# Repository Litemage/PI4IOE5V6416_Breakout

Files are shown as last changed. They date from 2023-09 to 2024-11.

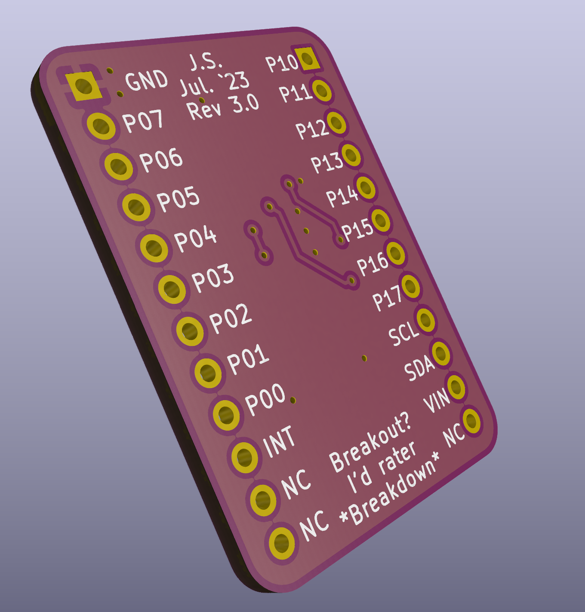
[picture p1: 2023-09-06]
Photos/Board_Back.png

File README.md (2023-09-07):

# Repo Description
This project contains a breakout board for the Diodes Inc. PI4IOE5V6416 16 channel I2C I/O expander, as well as a C driver, for easier incorporation into your projects.

[The datasheet can be found here](https://www.diodes.com/assets/Datasheets/PI4IOE5V6416.pdf).

# Hardware
The ECad tool of choice is KiCad for this project. 

Manufacturing files for revision 3.0 are available in the **/Manufacturing** directory.

Photos of the board are available in **/photos**

The schematic is available in the root directory as a pdf. 

# Driver \(C\)
The C driver is designed to be implementation-agnostic. I recommend reading through the header files to gain a better understanding of the driver itself, and what's available. Regardless, the driver works off of a handle principle:

You create a device handle that is populated with call-backs to all the different functions needed to communicate with the device (read / write). 

This handle is then passed to all the functions in the public API which read/write to the device.

There is currently one driver implementation example under **/Examples**. Open an issue for another example if the simple one isn't enough as a quick-start to the driver.

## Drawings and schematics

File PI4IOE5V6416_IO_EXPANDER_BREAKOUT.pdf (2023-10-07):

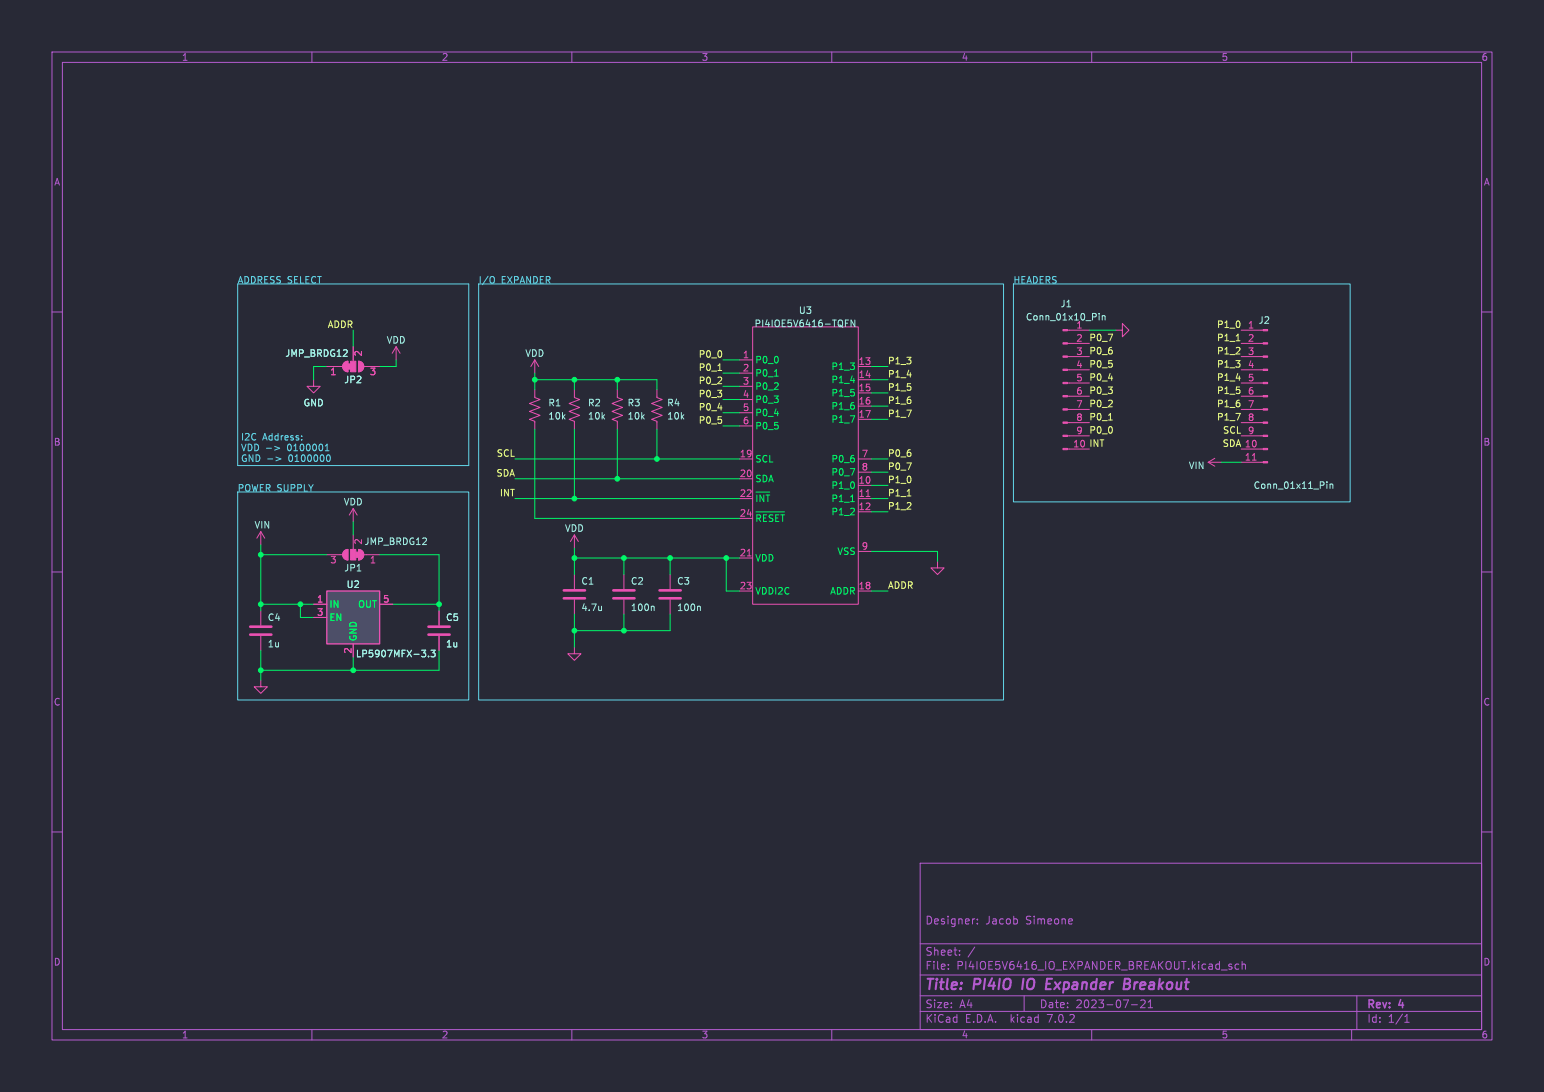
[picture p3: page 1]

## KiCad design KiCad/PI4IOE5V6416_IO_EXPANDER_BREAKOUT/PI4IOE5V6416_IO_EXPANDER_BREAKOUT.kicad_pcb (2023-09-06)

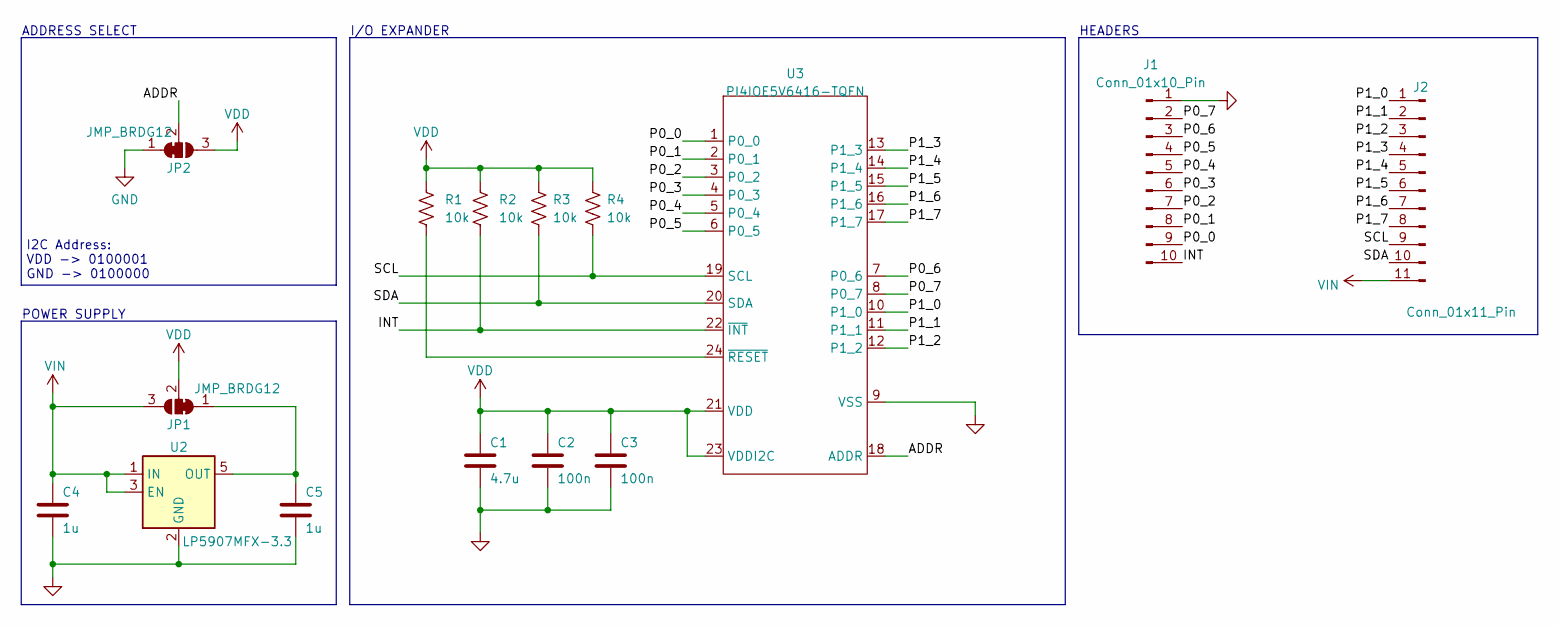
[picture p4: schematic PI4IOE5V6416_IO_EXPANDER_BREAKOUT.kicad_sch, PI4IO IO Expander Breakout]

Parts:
C1: 4.7u; C_0603_1608Metric
C2, C3: 100n; C_0603_1608Metric
C4, C5: 1u; C_0603_1608Metric
J1: Conn_01x10_Pin; PinHeader_1x10_P2.54mm_Vertical
J2: Conn_01x11_Pin; PinHeader_1x11_P2.54mm_Vertical
JP1, JP2: JMP_BRDG12; SolderJumper-3_P1.3mm_Bridged12_RoundedPad1.0x1.5mm
R1, R2, R3, R4: 10k; R_0603_1608Metric
U2: LP5907MFX-3.3; SOT-23-5
U3: PI4IOE5V6416-TQFN; TQFN-24-1EP_4x4mm_P0.5mm_EP2.1x2.1mm

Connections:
/ADDR: JP2.2 (C), U3.18 (ADDR)
/INT: J1.10, R2.2, U3.22 (~INT)
/P0_0: J1.9, U3.1 (P0_0)
/P0_1: J1.8, U3.2 (P0_1)
/P0_2: J1.7, U3.3 (P0_2)
/P0_3: J1.6, U3.4 (P0_3)
/P0_4: J1.5, U3.5 (P0_4)
/P0_5: J1.4, U3.6 (P0_5)
/P0_6: J1.3, U3.7 (P0_6)
/P0_7: J1.2, U3.8 (P0_7)
/P1_0: J2.1, U3.10 (P1_0)
/P1_1: J2.2, U3.11 (P1_1)
/P1_2: J2.3, U3.12 (P1_2)
/P1_3: J2.4, U3.13 (P1_3)
/P1_4: J2.5, U3.14 (P1_4)
/P1_5: J2.6, U3.15 (P1_5)
/P1_6: J2.7, U3.16 (P1_6)
/P1_7: J2.8, U3.17 (P1_7)
/SCL: J2.9, R4.2, U3.19 (SCL)
/SDA: J2.10, R3.2, U3.20 (SDA)
GND: C1.2, C2.2, C3.2, C4.2, C5.2, J1.1, JP2.1 (A), U2.2 (GND), U3.9 (VSS)
unnamed: C5.1, JP1.1 (A), U2.5 (OUT)
unnamed: R1.2, U3.24 (~RESET)
VDD: C1.1, C2.1, C3.1, JP1.2 (C), JP2.3 (B), R1.1, R2.1, R3.1, R4.1, U3.21 (VDD), U3.23 (VDDI2C)
VIN: C4.1, J2.11, JP1.3 (B), U2.1 (IN), U2.3 (EN)

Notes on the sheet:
POWER SUPPLY
ADDRESS SELECT
HEADERS
I2C Address: VDD -> 0100001 GND -> 0100000
I/O EXPANDER

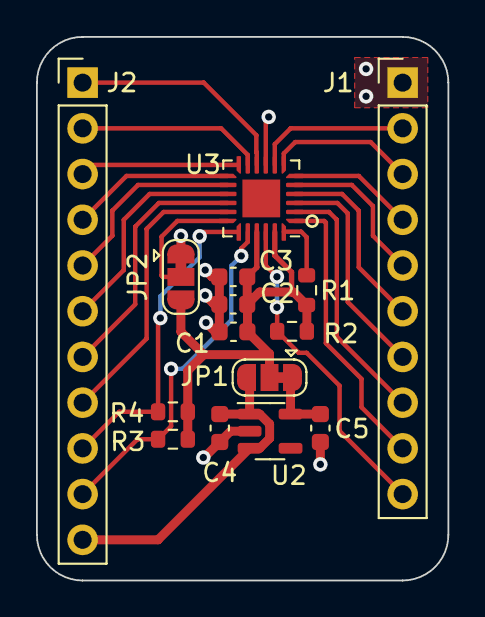
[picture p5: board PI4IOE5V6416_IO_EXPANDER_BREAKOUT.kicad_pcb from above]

Board: 2 copper layers, 22.9 x 30.2 mm, 15 parts (0 on the bottom side), 25 nets.

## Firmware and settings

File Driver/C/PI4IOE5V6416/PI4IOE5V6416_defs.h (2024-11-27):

/**
 * \file PI4IOE5V6416_defs.h
 * \authors Jacob Simeone (jsimeone0105@gmail.com)
 * \brief Macros for PI4IOE5V6416 driver
 * \date 2023-07-22
 * 
 */

#ifndef __PI4IOE5V6416_DEFS_H__
#define __PI4IOE5V6416_DEFS_H__

#include <stdint.h>
#include <stddef.h>

// DEFINITIONS =================================================================

/**
 * 
 * Signals to I2C read function to not specify the register address, resulting in
 * the driver reading from the "current" register, stored on the IC's register pointer
 * register. 
 * 
 * Only valid for reading
 * 
 */

#define PI4IO_REG_CURRENT         (0xFF)

#define PI4IO_ADDR_PRM            (0x20)
#define PI4IO_ADDR_SEC            (0x21)

// ========== Errors ==========

#define PI4IO_ERR_BASE            (0)
#define PI4IO_OK                  (PI4IO_ERR_BASE - 0)
#define PI4IO_ERR_COMM            (PI4IO_ERR_BASE - 1) // Communication to hardware failed
#define PI4IO_ERR_NULL_PTR        (PI4IO_ERR_BASE - 2)
#define PI4IO_ERR_ARG             (PI4IO_ERR_BASE - 3) // Invalid argument
#define PI4IO_ERR_CONFIG          (PI4IO_ERR_BASE - 4) // Configuration error
#define PI4IO_ERR_ADDR            (PI4IO_ERR_BASE - 5) // Invalid address

// ========== Registers ==========

#define PI4IO_REG_INPUT_PORT_0    (0x00)
#define PI4IO_REG_INPUT_PORT_1    (0x01)
#define PI4IO_REG_OUTPUT_PORT_0   (0x02)
#define PI4IO_REG_OUTPUT_PORT_1   (0x03)
#define PI4IO_REG_POLARITY_INV_0  (0x04)
#define PI4IO_REG_POLARITY_INV_1  (0x05)
#define PI4IO_REG_CONFIG_0        (0x06)
#define PI4IO_REG_CONFIG_1        (0x07)
#define PI4IO_REG_DRV_STREN_0_0   (0x40)
#define PI4IO_REG_DRV_STREN_0_1   (0x41)
#define PI4IO_REG_DRV_STREN_1_0   (0x42)
#define PI4IO_REG_DRV_STREN_1_1   (0x43)
#define PI4IO_REG_INPUT_LATCH_0   (0x44)
#define PI4IO_REG_INPUT_LATCH_1   (0x45)
#define PI4IO_REG_PU_PD_EN_0      (0x46)
#define PI4IO_REG_PU_PD_EN_1      (0x47)
#define PI4IO_REG_PU_PD_CFG_0     (0x48)
#define PI4IO_REG_PU_PD_CFG_1     (0x49)
#define PI4IO_REG_INT_MASK_0      (0x4A)
#define PI4IO_REG_INT_MASK_1      (0x4B)
#define PI4IO_REG_INT_STAT_0      (0x4C)
#define PI4IO_REG_INT_STAT_1      (0x4D)
#define PI4IO_REG_OUTPUT_PORT_CFG (0x4F)

#define PI4IO_REG_MAX             (PI4IO_REG_OUTPUT_PORT_CFG)

// TYPE DEFINITIONS ============================================================

/** 
 * Implement I2C communication with this function
 * 
 * Reference datasheet for more information: https://www.mouser.com/datasheet/2/115/PI4IOE5V6416-1488866.pdf
 * 
 * The process for writing to the PI4IOE5V6416 is:
 * 
 * - Master puts start condition onto bus
 * - Master puts slave address onto bus, with the write bit
 * - Slave acknowledges 
 * - Master puts register address on bus
 * - Slave acknowledges
 * - Master puts register data onto the bus
 * - Slave acknowledges
 * - Master puts stop condition on the bus
 * 
 * Ensure to reference datasheet for further details
 * 
 * Return -1 on failure, and 0 on success
 * 
*/
typedef int (*pi4io_i2c_write_fptr_t)(uint8_t addr, const uint8_t reg, const uint8_t val);

/**
 * Implement I2C communication with this function
 * 
 * Reference datasheet for more information: https://www.mouser.com/datasheet/2/115/PI4IOE5V6416-1488866.pdf
 * 
 * The process for reading data from the PI4IOE5V6416 is:
 * 
 * - Master puts start condition on the bus
 * - Master puts slave address on the bus with write bit
 * - Slave acknowledges
 * - Master puts register address on bus
 * - Slave acknowledges
 * - Master puts start condition on bus
 * - Master puts slave address on the bus with read bit
 * - Slave acknowledges
 * - Slave submits K bytes of read data
 * - Master acknowledges, unless enough data has been received, in which case the master will not-acknowledge
 * - Master puts stop condition on bus
 * 
 * Ensure to reference datasheet for further details
 * 
 * Return -1 on failure, and 0 on success
 * 
 */
typedef int (*pi4io_i2c_read_fptr_t)(uint8_t addr, const uint8_t reg, uint8_t *pBuf, const size_t bufSize);

/**
 * \brief Pointer to a function that controls the reset pin. If null, user is responsible for 
 * resetting device. 
 * 
 * NOTE: set to null if reset pin is not used. Note this will stop the driver from resetting the 
 * device on every init call
 * 
 * \param pinState Represents the requested state of the reset pin. 0 for low, 1 for high.
 * 
 */
typedef int (*pi4io_reset_pin_fptr_t)(uint8_t addr, const uint8_t pinState);

/**
 * \brief Delay for x microseconds
 * 
 * \param delay Number of uS to delay.
 * 
 */
typedef void (*pi4io_delay_us_fptr_t)(const uint64_t delay);

typedef struct
{
   pi4io_i2c_write_fptr_t write;  // I2C Write callback
   pi4io_i2c_read_fptr_t read;    // I2C Read Callback
   pi4io_reset_pin_fptr_t reset;  // Reset gpio function
   pi4io_delay_us_fptr_t delayUs; // Delay for some microseconds
   uint8_t addr;
} pi4io_dev_t;

typedef enum
{
   PI4IO_PORT_0 = 0,
   PI4IO_PORT_1 = 1,

   PI4IO_PORT_MAX,
} pi4io_port_num_t;
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

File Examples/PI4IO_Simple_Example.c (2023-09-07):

/**
 *
 * ========================= LICENSE =============================
 *
 * Licensed under the Apache License, Version 2.0 (the "License");
 * you may not use this file except in compliance with the License.
 * You may obtain a copy of the License at
 *
 *     http://www.apache.org/licenses/LICENSE-2.0
 *
 * Unless required by applicable law or agreed to in writing, software
 * distributed under the License is distributed on an "AS IS" BASIS,
 * WITHOUT WARRANTIES OR CONDITIONS OF ANY KIND, either express or implied.
 * See the License for the specific language governing permissions and
 * limitations under the License.
 *
 * ===============================================================
 *
 * @file PI4IO_Example.c
 * @author Jacob Simeone (jsimeone0105@gmail.com)
 *
 * @brief An example demonstrating the use of the PI4IOE5V6416 C driver included
 * in the breakout board repository found at (as of date on this file):
 *
 * https://github.com/Litemage/PI4IOE5V6416_Breakout
 *
 * You will need to implement some functions specific to your platform first,
 * before the demo can work.
 *
 * To use the demo, you can then either copy/paste the code in the
 * "main" function to your own "main" (along with the other contents of this
 * file) or change the name to something other than "main", and call this
 * example's "main" from your code.
 *
 * Please note that this example's "main" is blocking.
 *
 * The data sheet for the PI4IOE5V6416 can be found here (as of date on this
 * file):
 *
 * https://www.diodes.com/assets/Datasheets/PI4IOE5V6416.pdf
 *
 * @version 1.0
 * @date 2023-09-06
 *
 */

#include "PI4IOE5V6416.h"
#include "PI4IOE5V6416_defs.h"
#include <stdint.h>

// ==================== STATIC VARIABLES ====================
/**
 * These are statically-allocated variables that are needed with every public
 * API call, initialize / store them however you want, but statically allocating
 * them at the global scope isn't a bad idea.
 */

static pi4io_dev_t pi4io = {};

/**
 * This is an example of a configuration structure that is used to configure
 * the I/O expander, by each port.
 */

// PORT 0 ON EXPANDER
pi4io_port_cfg_t port0Conf = {
    .outputCfg = PI4IO_OUT_OPNDRN, // Outputs are open-drain.
    .pinConfig =
        {
            [0] =
                {
                    .pinDir = PI4IO_PIN_OUT, // Configure direction as output
                },
            [1] =
                {
                    .pinDir = PI4IO_PIN_OUT, // Configure direction as an output
                },
            [2] =
                {
                    .pinDir = PI4IO_PIN_IN, // Configure pin as an input
                    .puPd = PI4IO_PD,       // Configure this pin to pull down
                },
            /* This pin can be thought of as configured as an active low input,
               like the rest of the pins */
            [3] =
                {
                    .pinDir = PI4IO_PIN_IN,       // Input
                    .polarity = PI4IO_PIN_INVERT, // Inverted state in input
                                                  //  register. Logical high on
                                                  //  pin = 0. Logical low = 1
                    .puPd = PI4IO_PU,             // Pull-up this pin
                },
            [4] =
                {
                    .pinDir = PI4IO_PIN_IN,
                    .polarity = PI4IO_PIN_INVERT,
                    .puPd = PI4IO_PU,
                },
            [5] =
                {
                    .pinDir = PI4IO_PIN_IN,
                    .polarity = PI4IO_PIN_INVERT,
                    .puPd = PI4IO_PU,
                },
            [6] =
                {
                    .pinDir = PI4IO_PIN_IN,
                    .polarity = PI4IO_PIN_INVERT,
                    .puPd = PI4IO_PU,
                },
            [7] =
                {
                    .pinDir = PI4IO_PIN_IN,
                    .polarity = PI4IO_PIN_INVERT,
                    .puPd = PI4IO_PU,
                },

        },
};

// ==================== CALLBACK FUNCTIONS ====================
/**
 * These functions need to be defined per-implementation, and describe how to
 * read & write over i2c, how to wait, and how to toggle the reset pin on the
 * I/O expander.
 *
 * Details for the I2C reading & writing interactions can be found on the
 * data sheet.
 */

static int pi4io_i2c_write(const uint8_t reg, const uint8_t val) {
  /**
   * TODO Implement: Write to a register
   */
}

static int pi4io_i2c_read(const uint8_t reg, uint8_t *pBuf,
                          const size_t bufSize) {
  /**
   * TODO Implement: Read from a register
   */
}

static int pi4io_set_reset_pin(const uint8_t pinState) {
  /**
   * TODO Implement: Set reset pin to given pinState
   */
}

static void pi4io_delay_uS(const uint8_t delay) {
  /**
   * TODO Implement: delay some number of uS
   */
}

// ==================== EXAMPLE-SPECIFIC FUNCTIONS ====================

/**
 * @brief Delay a given number of mS (used for this example's "main" function)
 *
 * @param mS
 */
delay_mS(uint32_t mS) {
  /**
   * TODO Implement: delay some number of mS
   */
}

// ==================== INITIALIZATION ====================

/**
 * @brief A demonstration on how you might go about initializing the I/O
 * expander
 *
 * @return int The result of the various initialization & configuration API
 * calls
 */
static int pi4io_init() {

  int rslt = -1;
  pi4io.write = pi4io_i2c_write;
  pi4io.read = pi4io_i2c_read;
  pi4io.reset = pi4io_set_reset_pin;
  pi4io.delayUs = pi4io_delay_uS;

  /**
   * NOTE: If you don't assign the above functions to the device handle before
   * hand, the Init function will return an error
   */
  if ((rslt = PI4IOE5V6416Init(PI4IO_ADDR_PRM, &pi4io)) != 0) {
    return rslt;
  }

  /**
   * Use this function to configure by port, with the structure as initialized
   * above
   */
  if ((rslt = PI4IOConfigPort(PI4IO_PORT_0, &port0Conf, &pi4io)) != PI4IO_OK) {
    return rslt;
  }

  /** NOTE:
   * Not initializing port 1 causes it to be configured with initial register
   * values as described in the data sheet
   */
}

// ==================== MAIN PROGRAM ====================

/**
 * This is an example main function, you would replace the contents of
 * your main function with the statements in the function "main"'s body.
 *
 * Otherwise, rename this function and call it from your code.
 *
 * Connecting an LED (or another appropriate load) to pin 0 of port 0 will
 * result in a blink with a period of 2 seconds.
 */
int main() {
  int rslt = -1;
  rslt = pi4io_init();

  for (;;) {
    PI4IOWriteOutput(0, 0, 1, &pi4io);
    delay_mS(1000);
    PI4IOWriteOutput(0, 0, 0, &pi4io);
    delay_mS(1000);
  }
}

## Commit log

2023-09-06 Revision 4
    - Remove unnecessary pin headers
    [PI4IOE5V6416_IO_EXPANDER_BREAKOUT.kicad_pcb, PI4IOE5V6416_IO_EXPANDER_BREAKOUT.kicad_sch]
2023-09-07 Add driver example
2023-10-07 Fix Schematic
2024-11-19 Resolve potential bugs
    - FIX: Delay mircoseconds declared with 8-bit buffer
    - FIX: Potential infinitely recursive call (oops)
    [PI4IOE5V6416_defs.h]
